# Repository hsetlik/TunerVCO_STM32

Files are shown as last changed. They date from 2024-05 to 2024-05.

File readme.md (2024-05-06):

# Eurorack VCO with STM32-powered tuner

This repo contains the code, schematic, and PCB design for a full-featured voltage controlled oscillator with an OLED-based tuner in a 9HP Eurorack module. The VCO is
built around the [AS3340 IC from Alfa](https://www.alfarzpp.lv/eng/sc/AS3340.pdf), while the tuner is powered by an [STM32G030F6P6 microcontroller](https://www.st.com/en/microcontrollers-microprocessors/stm32g030f6.html).

## Background

This is an improved version of my earlier [tuner VCO module](https://github.com/hsetlik/TunerVCO). The old one runs on an ESP32 WROOM cannibalized from an unused dev board I had lying around, with firmware written in the Arduino framework.
The old ESP32 version works fine and sounds great, but I decided it was worthwhile to make an updated version based on a different MCU for a few reasons:

1. The ESP32 is far larger and more powerful than this little OLED tuner needs
2. The ESP32 WROOM module and its associated components (USB connector, USB-to-UART bridge, BJTs, etc.) take up a lot of space on the PCB, which necessitated a horrible design involving right-angle header pins on the first version.
3. I also put the pots too close together on the first version and the knobs didn't fit

## Hardware

I've included the full KiCad project inside the 'Schematic' directory. The PCB is 4 layers with the two internal layers as ground planes. Passives and semiconductors are in SMD packages except for the AS3340 which is in a DIP-16 package.

### 3340-based VCO

The analog part of the circuit is mostly derived from the [AS3340 datasheet](https://www.alfarzpp.lv/eng/sc/AS3340.pdf) and so isn't super interesting, but a couple things worth mentioning:

1. The two trim pots to adjust the 1V/oct tracking are mounted such that they can be adjusted from the front panel without taking the module out of the case
2. There's an output stage based on summing op-amps to both isolate the AS3340 from the output jacks and to bias all three waves to a +/- 5V range

### STM32-based tuner

Out of the whole STM32 lineup I settled on the STM32G030F6P6 because

1. The TSSOP-20 package is the perfect size for the module's form factor
2. It requires no external components
3. Relatively low cost

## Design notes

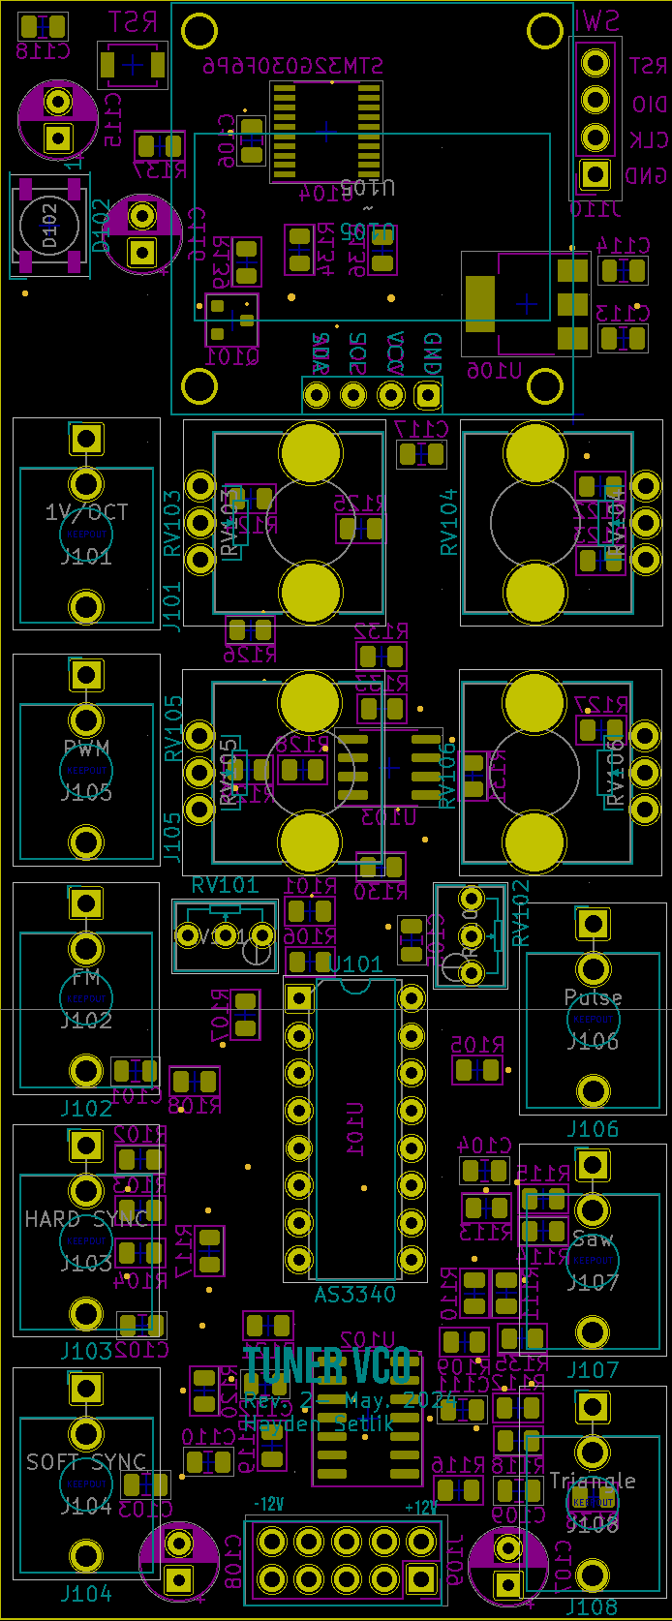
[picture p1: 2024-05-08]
Panel/BoardImg.png

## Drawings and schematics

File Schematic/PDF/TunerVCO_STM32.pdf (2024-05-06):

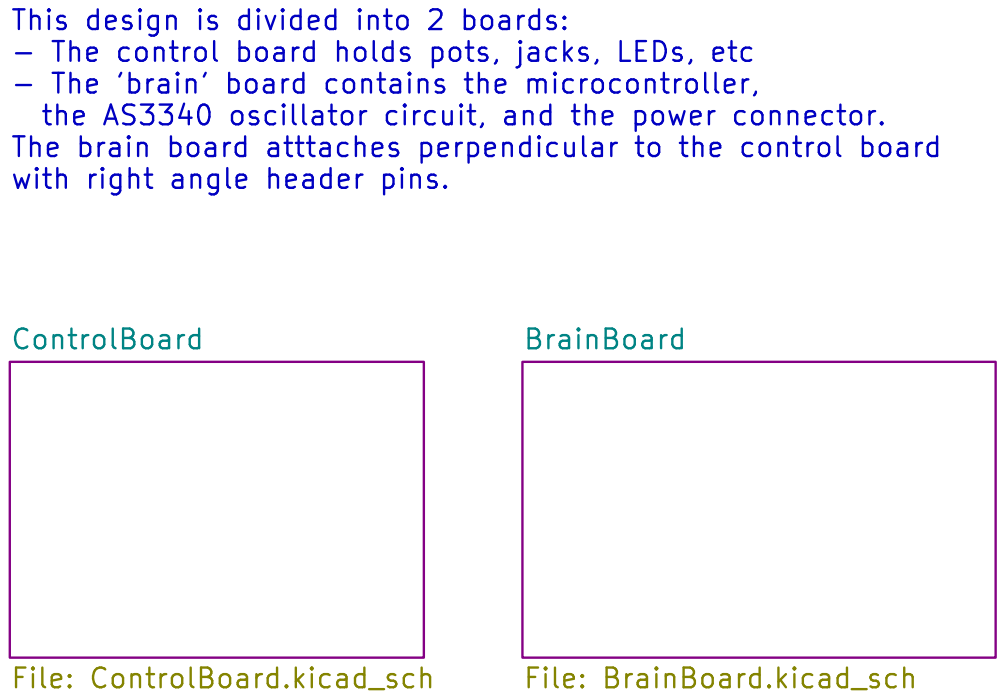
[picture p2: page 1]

File: TunerVCO.kicad_sch Sheet: / Hayden Setlik

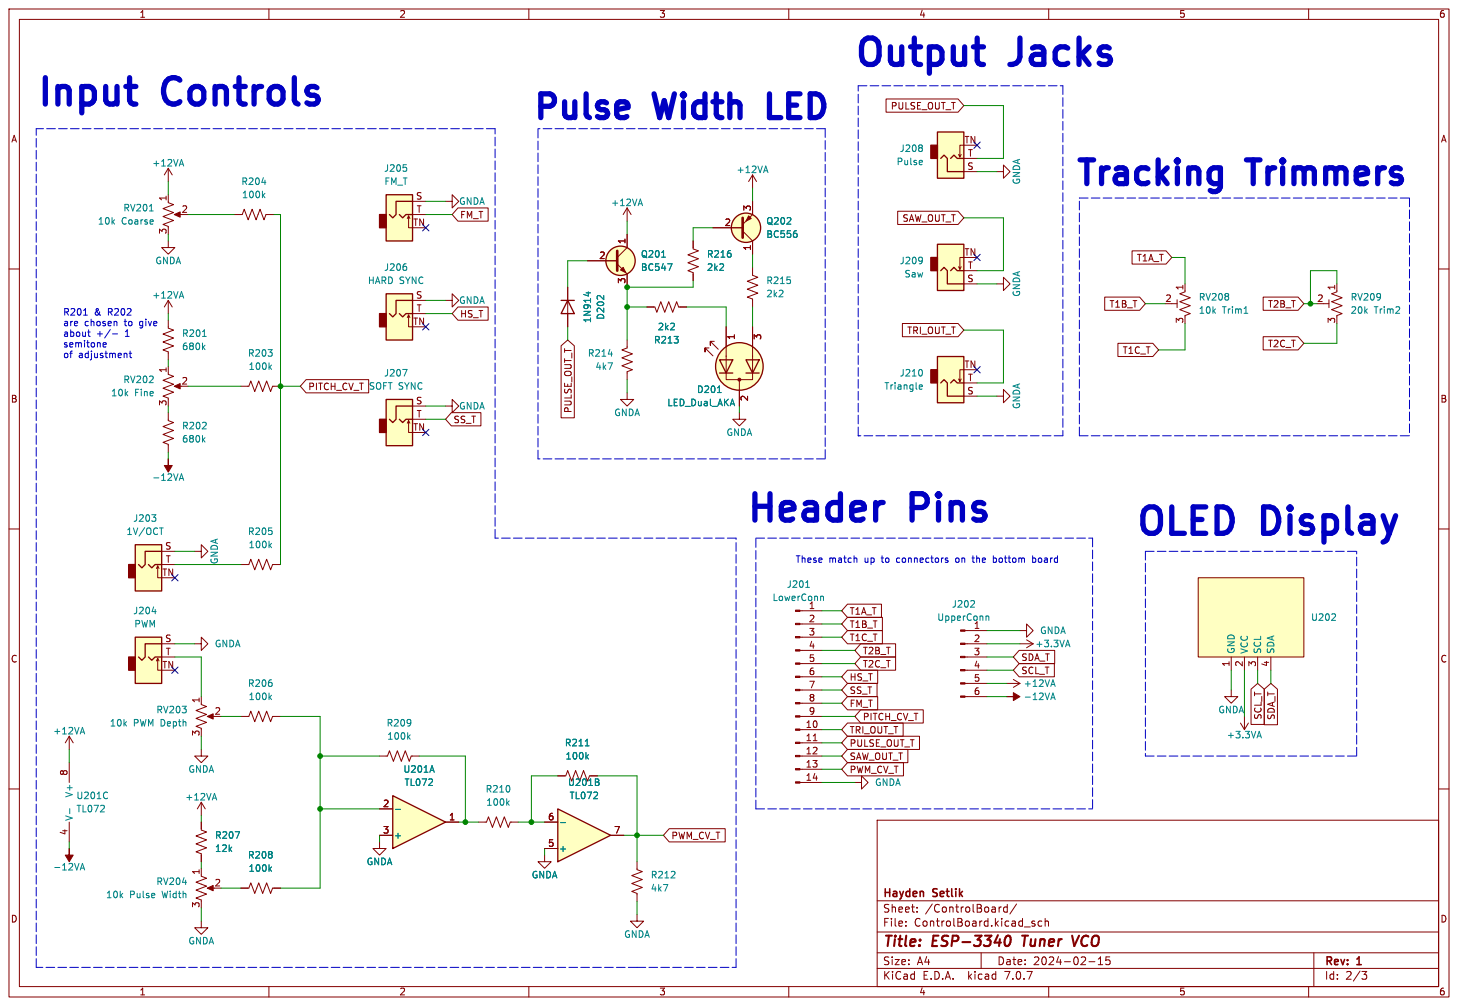
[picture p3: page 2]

are chosen to give
semitone
of adjustment

File: ControlBoard.kicad_sch Sheet: /ControlBoard/ Hayden Setlik

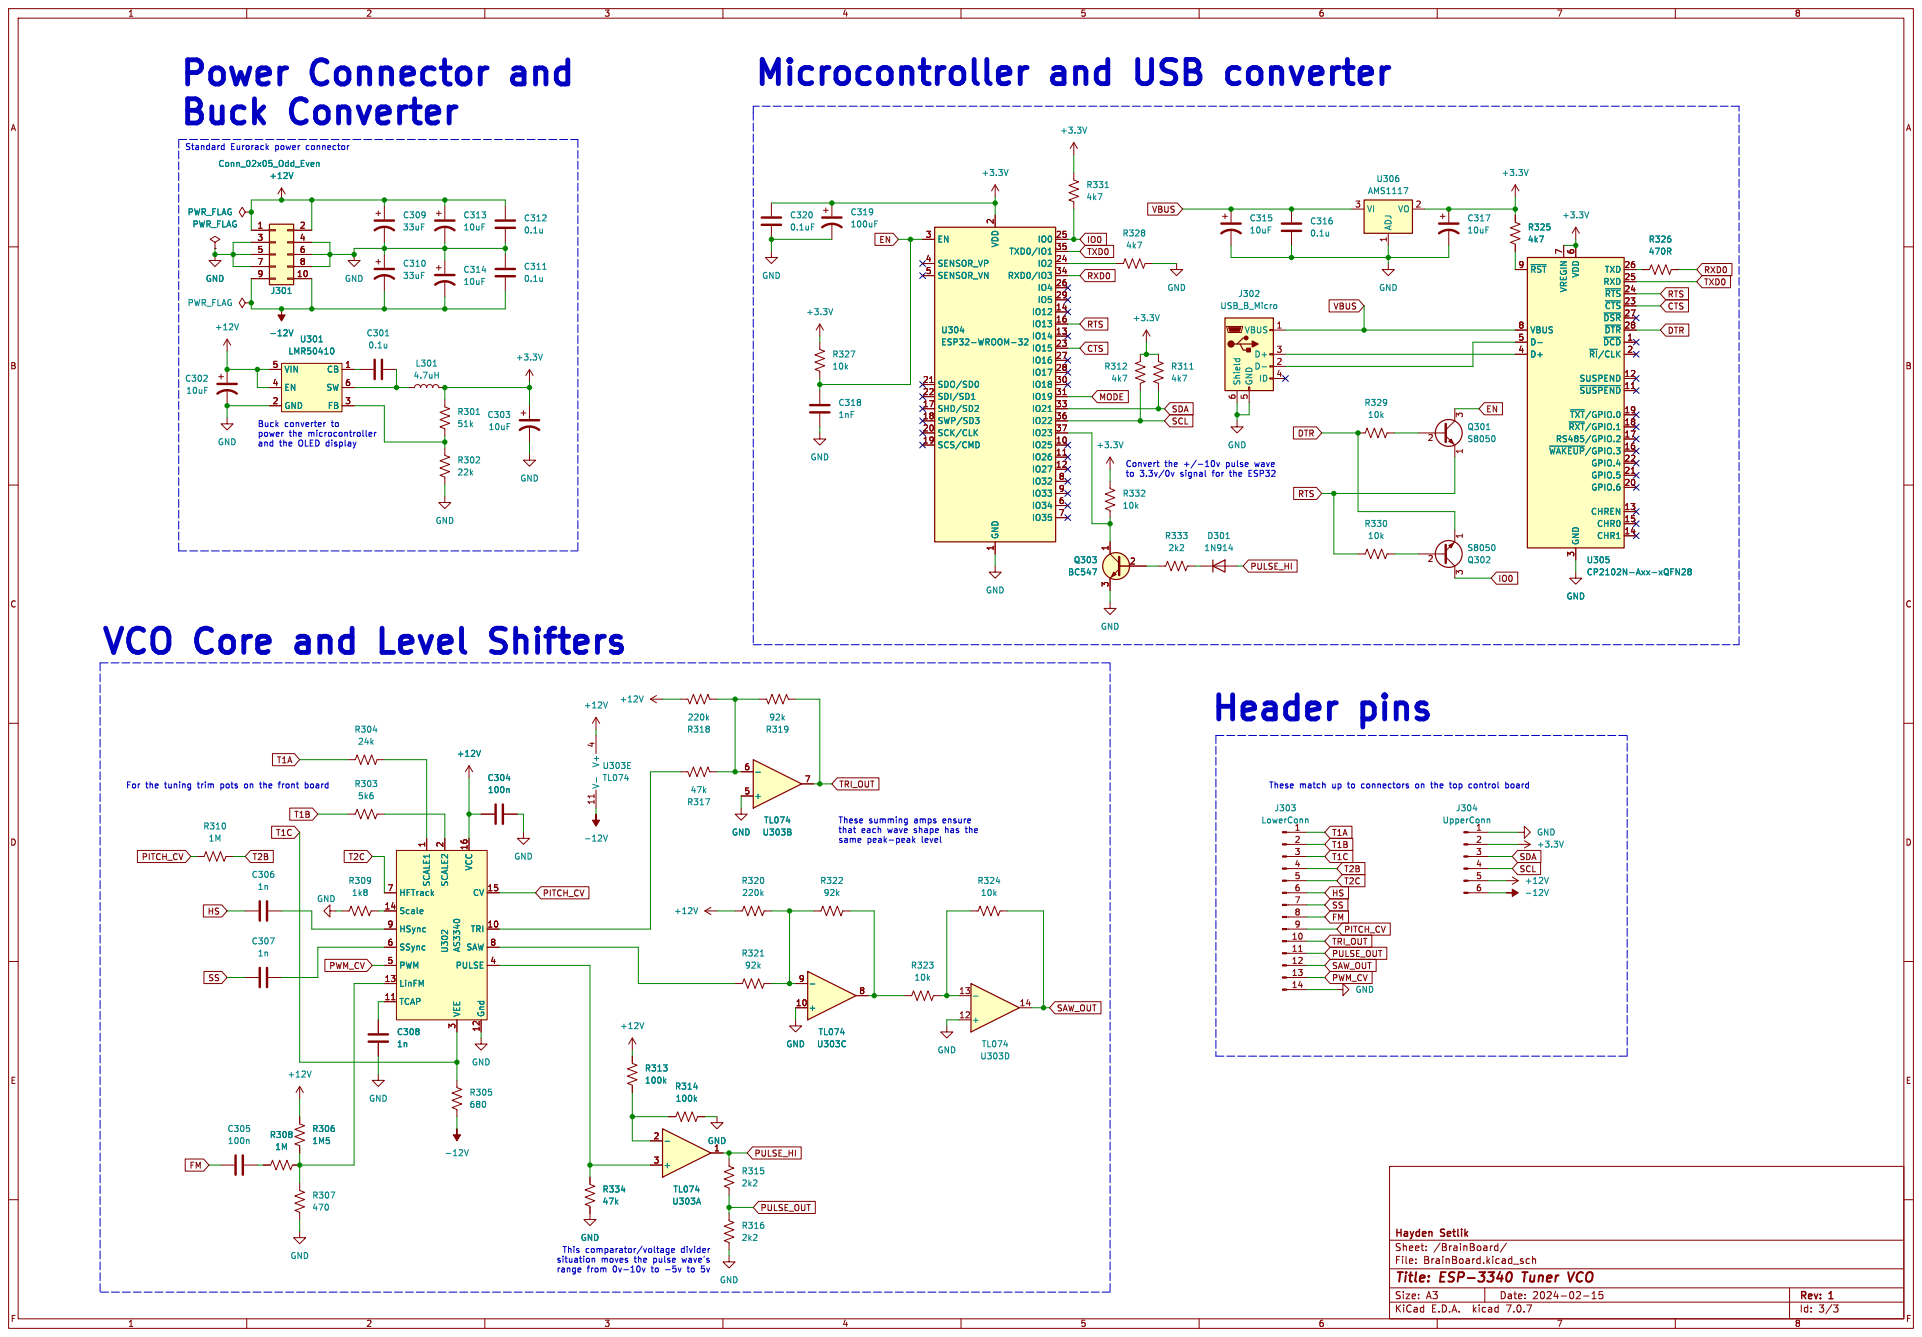
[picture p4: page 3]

2 SCK/CLK 20 SDO/SD0 21 SDI/SD1 22

power the microcontroller and the OLED display

VCO Core and Level Shifters

These summing amps ensure
that each wave shape has the

3 PULSE 4 PWM 5 SSync 6 HFTrack 7 SAW 8 HSync 9 R306
GND

3 PULSE 4 PWM 5 SSync 6 HFTrack 7 SAW 8 HSync 9 U302 AS3340

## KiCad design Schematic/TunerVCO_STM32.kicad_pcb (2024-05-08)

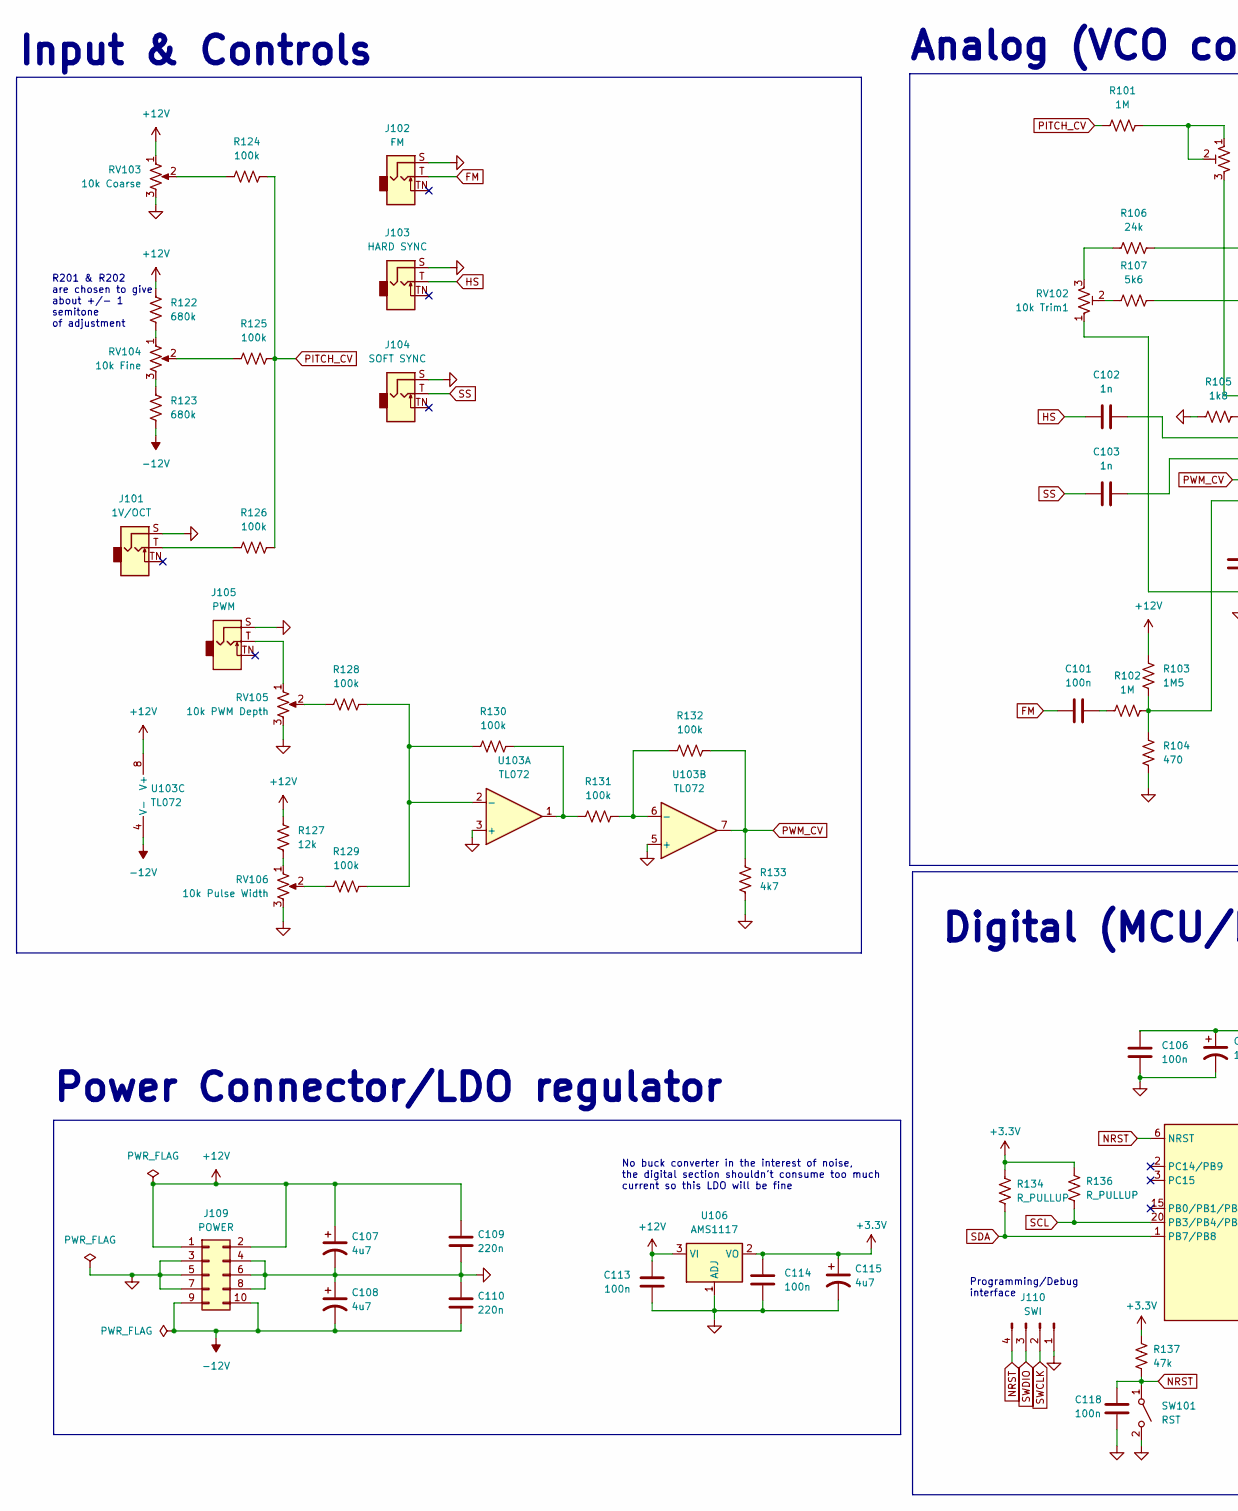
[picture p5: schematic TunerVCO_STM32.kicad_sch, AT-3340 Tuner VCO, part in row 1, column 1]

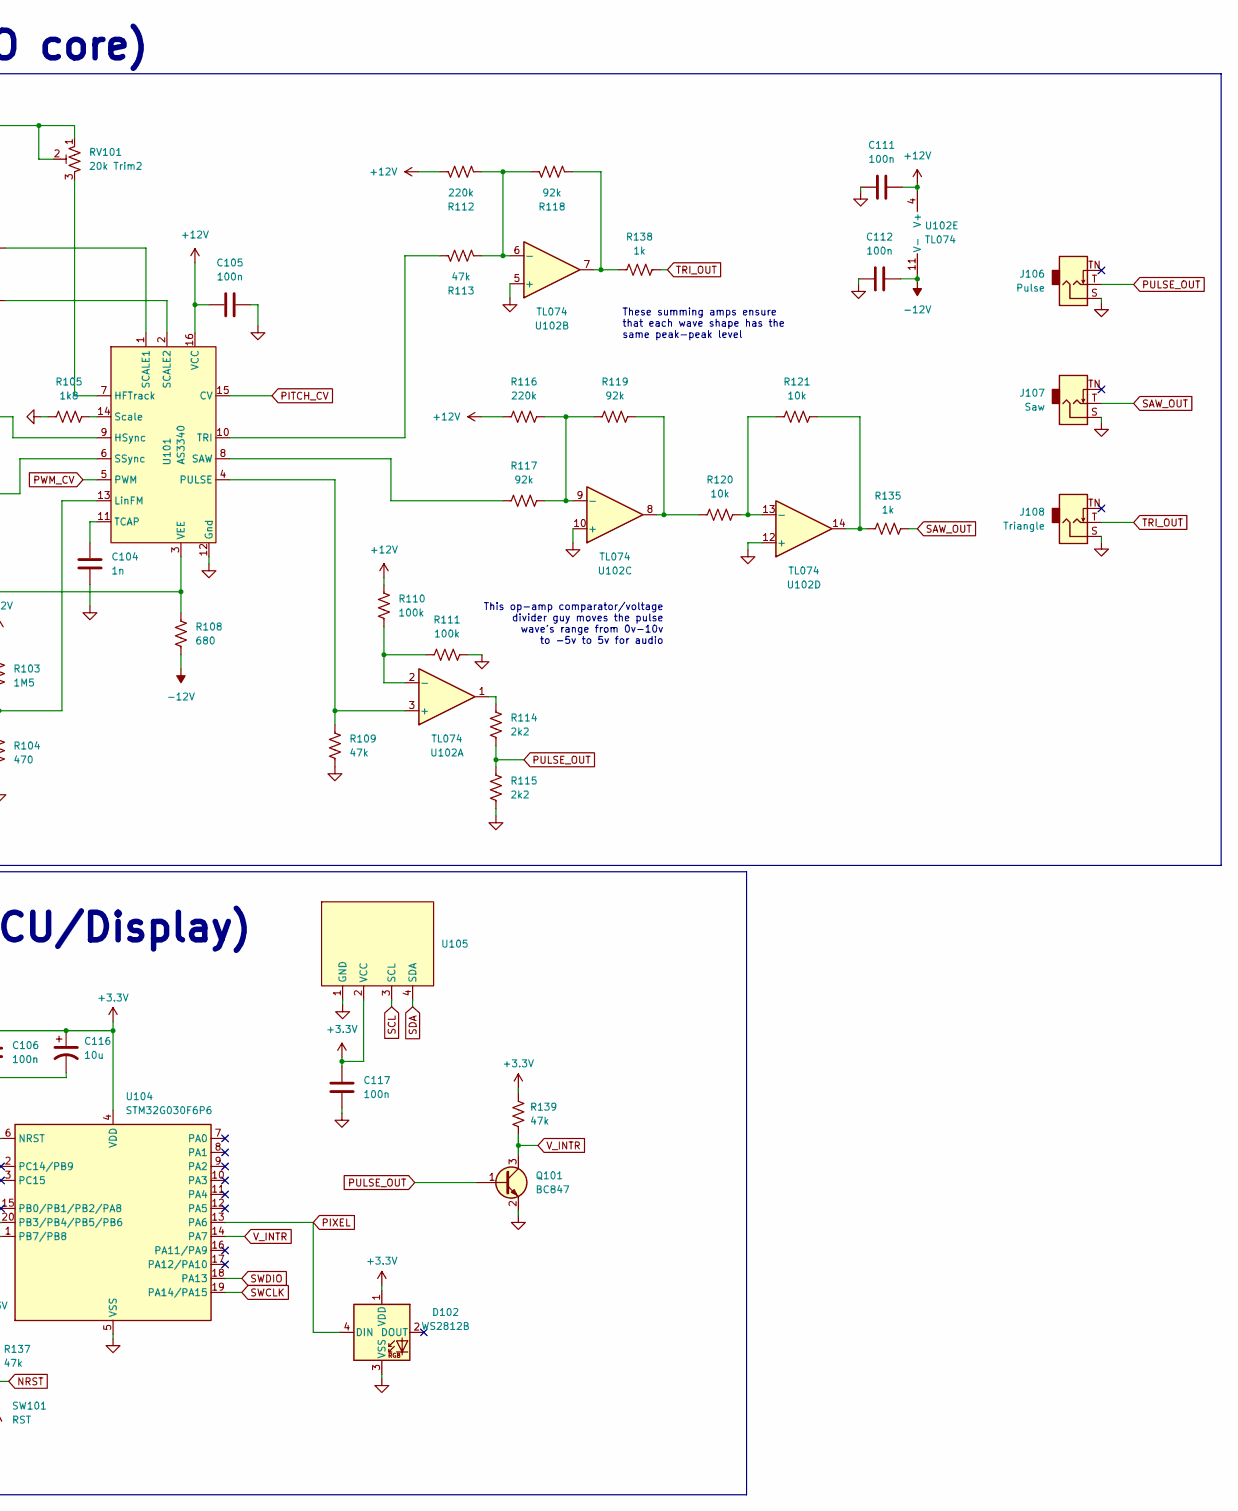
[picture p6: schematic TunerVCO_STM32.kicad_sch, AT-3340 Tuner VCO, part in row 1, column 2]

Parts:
C101, C105, C106, C111, C112, C113, C114, C117, C118: 100n; C_0805_2012Metric
C102, C103, C104: 1n; C_0805_2012Metric
C107, C108, C115: 4u7; CP_Radial_D5.0mm_P2.50mm
C109, C110: 220n; C_0805_2012Metric
C116: 10u; CP_Radial_D5.0mm_P2.50mm
D102: WS2812B; LED_WS2812B_PLCC4_5.0x5.0mm_P3.2mm
J101: 1V/OCT; Jack_3.5mm_QingPu_WQP-PJ398SM_Vertical_CircularHoles
J102: FM; Jack_3.5mm_QingPu_WQP-PJ398SM_Vertical_CircularHoles
J103: HARD SYNC; Jack_3.5mm_QingPu_WQP-PJ398SM_Vertical_CircularHoles
J104: SOFT SYNC; Jack_3.5mm_QingPu_WQP-PJ398SM_Vertical_CircularHoles
J105: PWM; Jack_3.5mm_QingPu_WQP-PJ398SM_Vertical_CircularHoles
J106: Pulse; Jack_3.5mm_QingPu_WQP-PJ398SM_Vertical_CircularHoles
J107: Saw; Jack_3.5mm_QingPu_WQP-PJ398SM_Vertical_CircularHoles
J108: Triangle; Jack_3.5mm_QingPu_WQP-PJ398SM_Vertical_CircularHoles
J109: POWER; PinHeader_2x05_P2.54mm_Vertical
J110: SWI; PinHeader_1x04_P2.54mm_Vertical
Q101: BC847; SOT-23
R101, R102: 1M; R_0805_2012Metric
R103: 1M5; R_0805_2012Metric
R104: 470; R_0805_2012Metric
R105: 1k8; R_0805_2012Metric
R106: 24k; R_0805_2012Metric
R107: 5k6; R_0805_2012Metric
R108: 680; R_0805_2012Metric
R109, R113, R137, R139: 47k; R_0805_2012Metric
R110, R111, R124, R125, R126, R128, R129, R130, R131, R132: 100k; R_0805_2012Metric
R112, R116: 220k; R_0805_2012Metric
R114, R115: 2k2; R_0805_2012Metric
R117, R118, R119: 92k; R_0805_2012Metric
R120, R121: 10k; R_0805_2012Metric
R122, R123: 680k; R_0805_2012Metric
R127: 12k; R_0805_2012Metric
R133: 4k7; R_0805_2012Metric
R134, R136: R_PULLUP; R_0805_2012Metric
R135, R138: 1k; R_0805_2012Metric
RV101: 20k Trim2; Potentiometer_Bourns_3266Y_Vertical
RV102: 10k Trim1; Potentiometer_Bourns_3266Y_Vertical
RV103: 10k Coarse; Potentiometer_Alps_RK09L_Single_Vertical
RV104: 10k Fine; Potentiometer_Alps_RK09L_Single_Vertical
RV105: 10k PWM Depth; Potentiometer_Alps_RK09L_Single_Vertical
RV106: 10k Pulse Width; Potentiometer_Alps_RK09L_Single_Vertical
SW101: RST; SW_SPST_B3U-1000P
U101: AS3340; DIP-16_W7.62mm
U102: TL074; SOIC-14_3.9x8.7mm_P1.27mm
U103: TL072; SOIC-8_3.9x4.9mm_P1.27mm
U104: STM32G030F6P6; TSSOP-20_4.4x6.5mm_P0.65mm
U105: SSD1306_OLED_128x64
U106: AMS1117; SOT-223-3_TabPin2

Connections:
+3.3V: C106.2, C114.2, C115.1, C116.1, C117.2, D102.1 (VDD), R134.2, R136.2, R137.1, R139.1, U104.4 (VDD), U105.2 (VCC), U106.2 (VO)
+12V: C105.1, C107.1, C109.2, C111.2, C113.2, J109.1, J109.2, R103.2, R110.1, R112.1, R116.1, R122.1, R127.2, RV103.1, U101.16 (VCC), U102.4 (V+), U103.8 (V+), U106.3 (VI)
-12V: C108.2, C110.1, C112.2, J109.9, J109.10, R108.1, R123.2, U102.11 (V-), U103.4 (V-)
FM: C101.1, J102.T
GND: C104.1, C105.2, C106.1, C107.2, C108.1, C109.1, C110.2, C111.1, C112.1, C113.1, C114.1, C115.2, C116.2, C117.1, C118.1, D102.3 (VSS), J101.S, J102.S, J103.S, J104.S, J105.S, J106.S, J107.S, J108.S, J109.3, J109.4, J109.5, J109.6, J109.7, J109.8, J110.1, Q101.2 (E), R104.1, R105.1, R109.2, R111.2, R115.2, R133.1, RV103.3, RV105.3, RV106.3, SW101.2 (B), U101.12 (Gnd), U102.5 (+), U102.10 (+), U102.12 (+), U103.3 (+), U103.5 (+), U104.5 (VSS), U105.1 (GND), U106.1 (ADJ)
HS: C102.1, J103.T
NRST: C118.2, J110.4, R137.2, SW101.1 (A), U104.6 (NRST)
unnamed: C101.2, R102.2
unnamed: J101.T, R126.1
unnamed: J105.T, RV105.1
unnamed: R101.2, RV101.1, RV101.2
unnamed: R106.1, RV102.3
unnamed: R107.1, RV102.2
unnamed: R114.1, U102.1
unnamed: R118.2, R138.1, U102.7
unnamed: R119.2, R120.1, U102.8
unnamed: R121.2, R135.1, U102.14
unnamed: R122.2, RV104.1
unnamed: R123.1, RV104.3
unnamed: R124.1, RV103.2
unnamed: R125.1, RV104.2
unnamed: R127.1, RV106.1
unnamed: R128.1, RV105.2
unnamed: R129.1, RV106.2
unnamed: R130.2, R131.1, U103.1
unnamed: RV101.3, U101.7 (HFTrack)
unnamed: C102.2, U101.9 (HSync)
unnamed: R102.1, R103.1, R104.2, U101.13 (LinFM)
unnamed: R109.1, U101.4 (PULSE), U102.3 (+)
unnamed: R117.1, U101.8 (SAW)
unnamed: R106.2, U101.1 (SCALE1)
unnamed: R107.2, U101.2 (SCALE2)
unnamed: C103.2, U101.6 (SSync)
unnamed: R105.2, U101.14 (Scale)
unnamed: C104.2, U101.11 (TCAP)
unnamed: R113.1, U101.10 (TRI)
unnamed: R108.2, RV102.1, U101.3 (VEE)
unnamed: R110.2, R111.1, U102.2 (-)
unnamed: R112.2, R113.2, R118.1, U102.6 (-)
unnamed: R116.2, R117.2, R119.1, U102.9 (-)
unnamed: R120.2, R121.1, U102.13 (-)
unnamed: R128.2, R129.2, R130.1, U103.2 (-)
unnamed: R131.2, R132.1, U103.6 (-)
PITCH_CV: R101.1, R124.2, R125.2, R126.2, U101.15 (CV)
PIXEL: D102.4 (DIN), U104.13 (PA6)
PULSE_OUT: J106.T, Q101.1 (B), R114.2, R115.1
PWM_CV: R132.2, R133.2, U101.5 (PWM), U103.7
SAW_OUT: J107.T, R135.2
SCL: R136.1, U104.20 (PB3/PB4/PB5/PB6), U105.3 (SCL)
SDA: R134.1, U104.1 (PB7/PB8), U105.4 (SDA)
SS: C103.1, J104.T
SWCLK: J110.2, U104.19 (PA14/PA15)
SWDIO: J110.3, U104.18 (PA13)
TRI_OUT: J108.T, R138.2
V_INTR: Q101.3 (C), R139.2, U104.14 (PA7)

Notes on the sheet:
Analog (VCO core)
Power Connector/LDO regulator
Programming/Debug interface
These summing amps ensure that each wave shape has the same peak-peak level
R201 & R202 are chosen to give about +/- 1 semitone of adjustment
Input & Controls
Digital (MCU/Display)
This op-amp comparator/voltage divider guy moves the pulse wave's range from 0v-10v to -5v to 5v for audio
No buck converter in the interest of noise, the digital section shouldn't consume too much current so this LDO will be fine

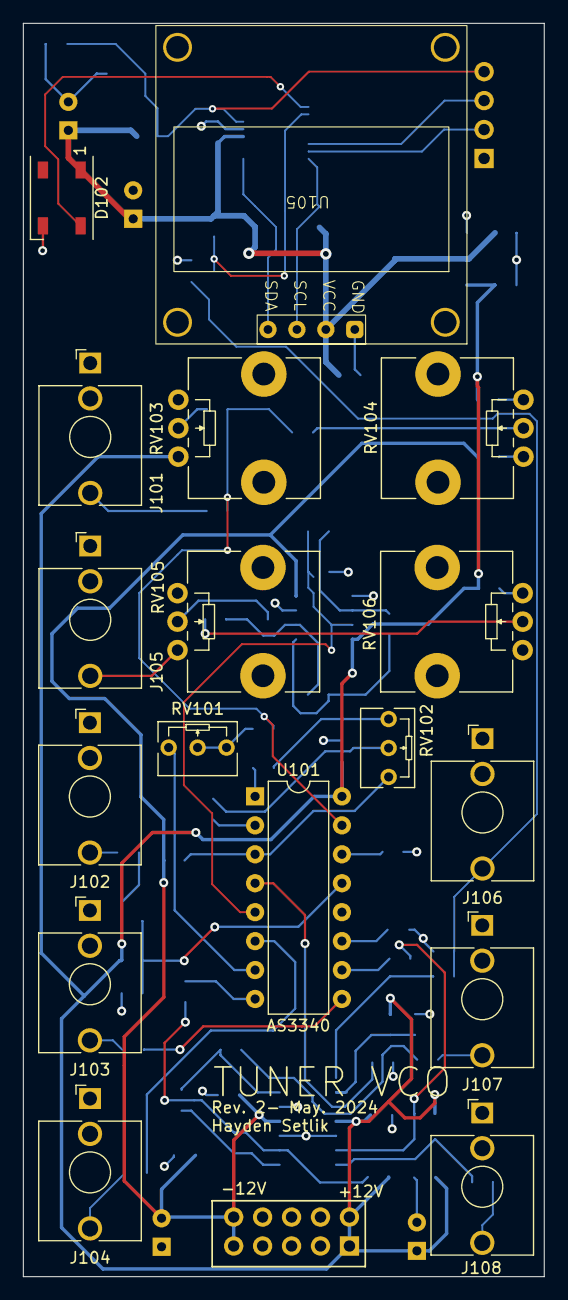
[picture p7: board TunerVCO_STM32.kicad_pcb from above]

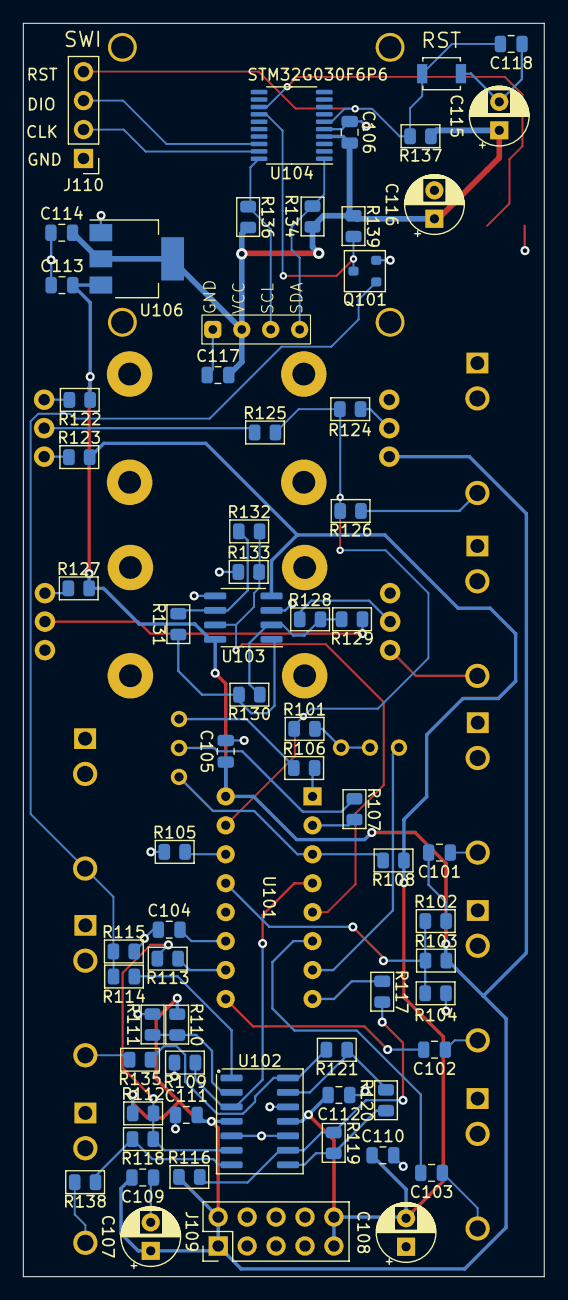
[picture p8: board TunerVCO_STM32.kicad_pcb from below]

Board: 4 copper layers, 45.7 x 110.0 mm, 82 parts (65 on the bottom side), 55 nets.

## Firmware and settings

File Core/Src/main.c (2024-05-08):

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
/* Includes ------------------------------------------------------------------*/
#include "main.h"

I2C_HandleTypeDef hi2c1;

TIM_HandleTypeDef htim16;
DMA_HandleTypeDef hdma_tim16_ch1;

/* USER CODE BEGIN PV */

// our two tuning buffers

uint32_t risingEdgeBuf[TUNING_BUF_SIZE];
head_t risingBufHead = 0;

uint32_t fallingEdgeBuf[TUNING_BUF_SIZE];
head_t fallingBufHead = 0;

float currentHz = 0.0f;

// neopixel stuff
pixel_data_t pixel;
float currentPulseWidth = 0.5f;
uint32_t wideColor;
uint32_t narrowColor;
// timing stuff
uint32_t lastDisplayUpdate = 0;
uint32_t lastPixelUpdate = 0;

/* USER CODE END PV */

void SystemClock_Config(void);
static void MX_GPIO_Init(void);
static void MX_DMA_Init(void);
static void MX_I2C1_Init(void);
static void MX_TIM16_Init(void);


/* USER CODE BEGIN PFP */
void updatePixel();
void updateOLED();

/* USER CODE END PFP */

/**
  * @brief  The application entry point.
  * @retval int
  */
int main(void)
{

  /* MCU Configuration--------------------------------------------------------*/

  /* Reset of all peripherals, Initializes the Flash interface and the Systick. */
  HAL_Init();

  /* Configure the system clock */
  SystemClock_Config();

  /* Initialize all configured peripherals */
  MX_GPIO_Init();
  MX_DMA_Init();
  MX_I2C1_Init();
  MX_TIM16_Init();
  /* USER CODE BEGIN 2 */
  // vars for the neopixels
  wideColor = getRGBColor(255, 0, 0);
  narrowColor = getRGBColor(0, 0, 255);

  /* USER CODE END 2 */

  /* Infinite loop */
  /* USER CODE BEGIN WHILE */
  uint32_t now = 0;
  while (1)
  {
    /* USER CODE END WHILE */
	now = HAL_GetTick();
	if(now - lastDisplayUpdate >= DISPLAY_INTERVAL_MS){
		updateOLED();
		lastDisplayUpdate = now;
	}

	if(now - lastPixelUpdate >= PIXEL_INTERVAL_MS){
		updatePixel();
		lastPixelUpdate = now;
	}

    /* USER CODE BEGIN 3 */
  }
  /* USER CODE END 3 */
}

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
/* USER CODE BEGIN 4 */

// ISRs
void HAL_GPIO_EXTI_Rising_Callback(uint16_t GPIO_Pin)
{
  /* Prevent unused argument(s) compilation warning */
  UNUSED(GPIO_Pin);
  triggerTuningUpdate(risingEdgeBuf, &risingBufHead);


}

void HAL_GPIO_EXTI_Falling_Callback(uint16_t GPIO_Pin)
{
  /* Prevent unused argument(s) compilation warning */
  UNUSED(GPIO_Pin);
  triggerTuningUpdate(fallingEdgeBuf, &fallingBufHead);

}

void HAL_TIM_PWM_PulseFinishedCallback(TIM_HandleTypeDef* htim){
	HAL_TIM_PWM_Stop_DMA(&htim16, TIM_CHANNEL_1);
	htim16.Instance->CCR1 = 0;
}

//------------------------------------------------------------

void updatePixel(){

	// step 1: calculate the current pulse width
	currentPulseWidth = getPulseWidth(risingEdgeBuf, &risingBufHead, fallingEdgeBuf, &fallingBufHead, 150);
	uint32_t rgb = lerpColors(narrowColor, wideColor, currentPulseWidth);
	// step 2. set the data
	setColor(&pixel, 0, rgb);
	//step 3. send to DMA
	HAL_TIM_PWM_Start_DMA(&htim16, TIM_CHANNEL_1, (uint32_t*)&pixel, 24);
}

void updateOLED(){
	//step 1: grip the hz
	currentHz = getCurrentHz(risingEdgeBuf, &risingBufHead);
	//step 2: send to display
	displayTuning(currentHz);

}


/* USER CODE END 4 */
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


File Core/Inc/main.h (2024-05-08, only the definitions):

#define NEOPIXEL_Pin GPIO_PIN_6
#define NEOPIXEL_GPIO_Port GPIOA
#define VCO_IN_Pin GPIO_PIN_7
#define VCO_IN_GPIO_Port GPIOA
#define DISPLAY_INTERVAL_MS 42
#define PIXEL_INTERVAL_MS 84

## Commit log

2024-05-06 added schematic and board to git
    [TunerVCO_STM32.kicad_pcb, TunerVCO_STM32.kicad_sch]
2024-05-08 Interrupt config, ISRs in main.c
2024-05-08 NeoPixel Timer/DMA stuff
    [TunerVCO_STM32.kicad_sch]
2024-05-08 pulse width LED
2024-05-08 main while loop, fixed pinout
    [TunerVCO_STM32.kicad_pcb]

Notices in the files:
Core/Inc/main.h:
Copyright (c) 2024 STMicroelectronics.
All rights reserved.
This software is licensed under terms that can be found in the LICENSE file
